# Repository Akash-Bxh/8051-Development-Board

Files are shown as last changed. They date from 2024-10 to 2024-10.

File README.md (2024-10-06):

# Building an 8051 Microcontroller Development Board
Material: KiCAD software, AT895S2, PCB, soldering kit, capacitor, resistor, display, 7-segment, push button, connector, buzzer, Ferric Chloride, Acetone, Fine abrasive sand paper, etc.

An 8051 Development Board is a hardware platform for projects involving the 8051 microcontroller. It includes the microcontroller, clock and reset circuits, power supply, I/O and peripheral interfaces (ADC, DAC), and supports various development tools. Users can write programs in assembly or high-level languages, compile them, and load them onto the board using assemblers and debuggers.

## Steps to make an 8051 Development Board:
* Design the Circuit: Use PCB design software like KiCAD to design the circuit and choose appropriate footprints for each component. Generate the Gerber files for the design.
* Print the Circuit on Raw PCB: Use the screen printing method to transfer the circuit design onto the raw PCB. Apply ink through a stencil and let it dry near warm air for 20-25 minutes.
* Etching Process: Submerge the PCB in ferric chloride solution to remove unwanted copper. After 10-15 minutes, clean the PCB with acetone to remove excess ink.
* Drilling: Drill holes in the PCB where electronic components will be mounted.
* Footprint Placement: Attach the printed component layout on the non-copper side to guide component placement.
* Soldering Components: Insert components on the PCB and solder them securely to the copper side.

## Applications and Uses of this 8051 Development Board
* Microcontroller Programming: It allows users to load and test programs written for the 8051 microcontroller, typically in assembly or C, through an assembler and debugger.
* Hardware Testing and Development: The board provides an environment for testing I/O ports and peripheral interfaces (ADC, DAC) connected to the 8051 microcontroller. It’s used for controlling devices or reading sensor data.
* Circuit Prototyping: The board is used for prototyping embedded system designs before transferring to a final PCB design for production.
* Peripheral Interfacing: You can connect and control components like sensors, displays, and actuators, making it suitable for hardware projects and experiments.
* Learning Platform: Ideal for education in embedded systems, giving students and developers hands-on experience with 8051 microcontrollers.

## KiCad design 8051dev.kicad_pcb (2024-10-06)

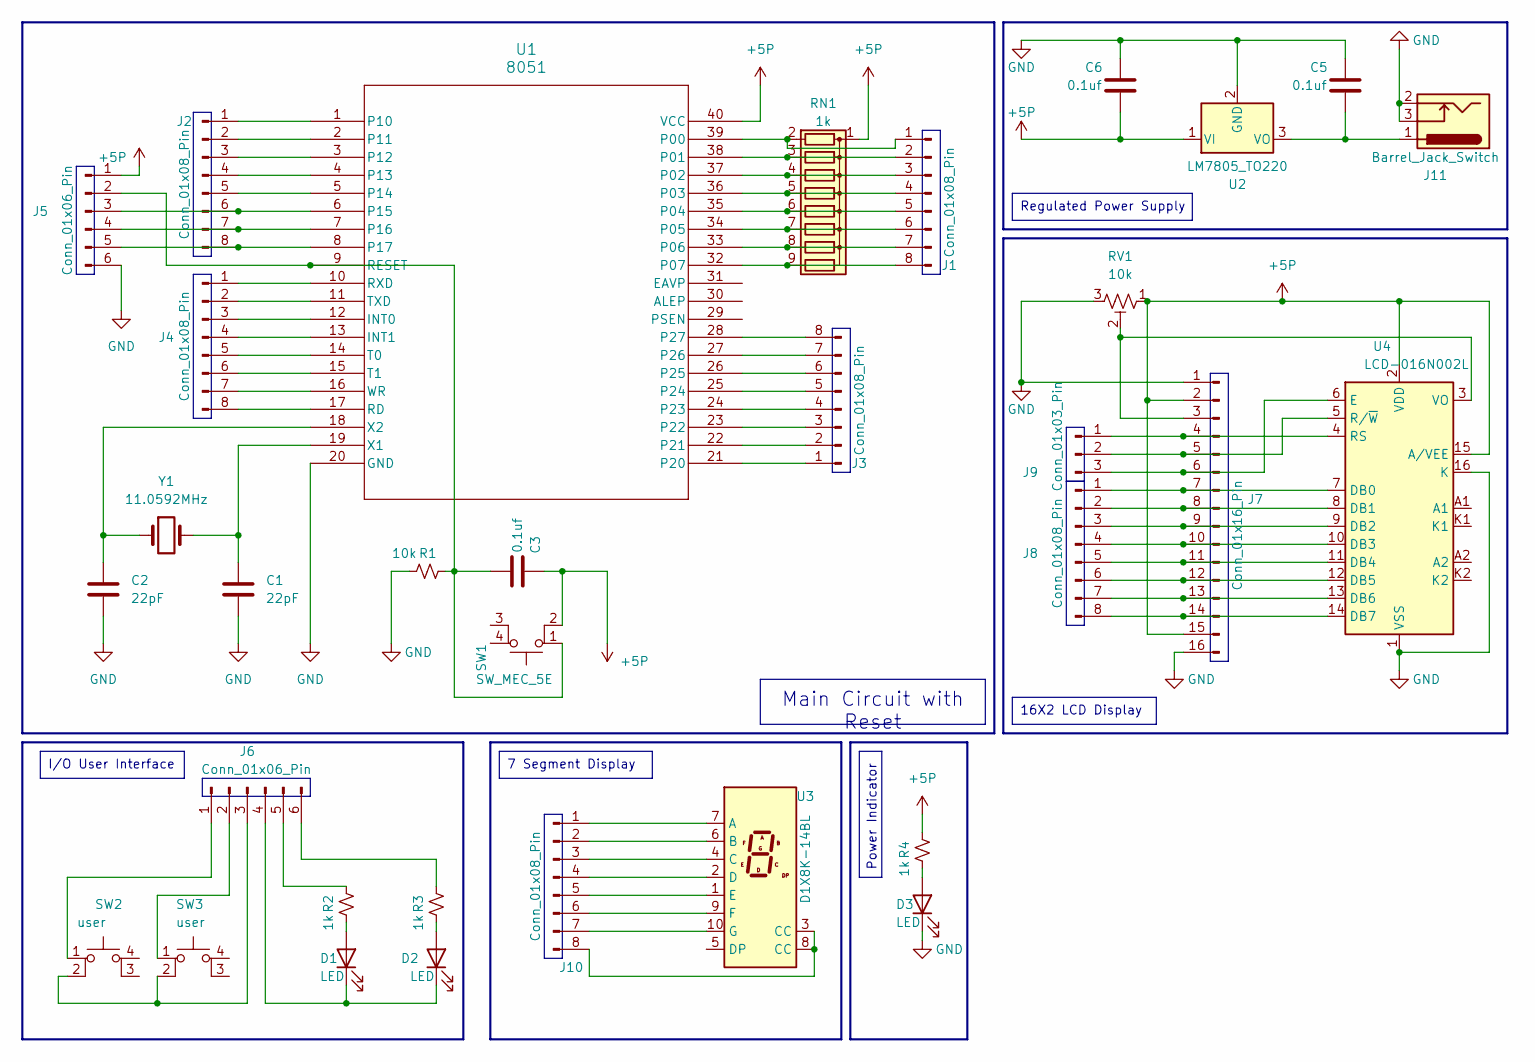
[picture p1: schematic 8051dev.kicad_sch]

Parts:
C1, C2: 22pF; C_Disc_D3.8mm_W2.6mm_P2.50mm
C3, C5, C6: 0.1uf; C_Disc_D3.8mm_W2.6mm_P2.50mm
D1, D2, D3: LED; LED_D5.0mm_Clear
J1, J2, J3, J4, J8, J10: Conn_01x08_Pin; PinHeader_1x08_P2.54mm_Vertical
J5, J6: Conn_01x06_Pin; PinHeader_1x06_P2.54mm_Vertical
J7: Conn_01x16_Pin; PinHeader_1x16_P2.54mm_Vertical
J9: Conn_01x03_Pin; PinHeader_1x03_P2.54mm_Vertical
J11: Barrel_Jack_Switch; BarrelJack_Horizontal
R1: 10k; R_Axial_DIN0207_L6.3mm_D2.5mm_P10.16mm_Horizontal
R2, R3: 1k; R_Axial_DIN0204_L3.6mm_D1.6mm_P2.54mm_Vertical
R4: 1k; R_Axial_DIN0207_L6.3mm_D2.5mm_P10.16mm_Horizontal
RN1: 1k; R_Array_SIP9
RV1: 10k; Potentiometer_ACP_CA6-H2,5_Horizontal
SW1: SW_MEC_5E; SW_PUSH_6mm_H4.3mm
SW2, SW3: user; SW_PUSH_6mm_H4.3mm
U1: 8051; DIP-40_W15.24mm
U2: LM7805_TO220; TO-220-3_Vertical
U3: D1X8K-14BL; 7SegmentLED_LTS6760_LTS6780
U4: LCD-016N002L
Y1: 11.0592MHz; Crystal_HC18-U_Vertical

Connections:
+5P: C3.1, C6.2, J5.1, J7.2, J7.15, R4.1, RN1.1 (common), RV1.1, SW1.2, U1.40 (VCC), U2.1 (VI), U4.2 (VDD), U4.15 (A/VEE); also elsewhere on the board
GND: C1.2, C2.1, C5.1, C6.1, D3.1 (K), J5.6, J7.1, J7.16, J11.2, J11.3, R1.2, RV1.3, U1.20 (GND), U2.2 (GND), U4.1 (VSS), U4.16 (K); also elsewhere on the board
unnamed: D1.2 (A), R2.2
unnamed: D1.1 (K), D2.1 (K), J6.4
unnamed: D2.2 (A), R3.2
unnamed: D3.2 (A), R4.2
unnamed: J1.1, RN1.2 (R1), U1.39 (P00)
unnamed: J1.2, RN1.3 (R2), U1.38 (P01)
unnamed: J1.3, RN1.4 (R3), U1.37 (P02)
unnamed: J1.4, RN1.5 (R4), U1.36 (P03)
unnamed: J1.5, RN1.6 (R5), U1.35 (P04)
unnamed: J1.6, RN1.7 (R6), U1.34 (P05)
unnamed: J1.7, RN1.8 (R7), U1.33 (P06)
unnamed: J1.8, RN1.9 (R8), U1.32 (P07)
unnamed: J2.1, U1.1 (P10)
unnamed: J2.2, U1.2 (P11)
unnamed: J2.3, U1.3 (P12)
unnamed: J2.4, U1.4 (P13)
unnamed: J2.5, U1.5 (P14)
unnamed: J2.6, J5.3, U1.6 (P15)
unnamed: J2.7, J5.4, U1.7 (P16)
unnamed: J2.8, J5.5, U1.8 (P17)
unnamed: J3.1, U1.21 (P20)
unnamed: J3.2, U1.22 (P21)
unnamed: J3.3, U1.23 (P22)
unnamed: J3.4, U1.24 (P23)
unnamed: J3.5, U1.25 (P24)
unnamed: J3.6, U1.26 (P25)
unnamed: J3.7, U1.27 (P26)
unnamed: J3.8, U1.28 (P27)
unnamed: J4.1, U1.10 (RXD)
unnamed: J4.2, U1.11 (TXD)
unnamed: J4.3, U1.12 (INT0)
unnamed: J4.4, U1.13 (INT1)
unnamed: J4.5, U1.14 (T0)
unnamed: J4.6, U1.15 (T1)
unnamed: J4.7, U1.16 (WR)
unnamed: J4.8, U1.17 (RD)
unnamed: C3.2, J5.2, R1.1, SW1.1, U1.9 (RESET)
unnamed: J6.1, SW2.1
unnamed: J6.2, SW3.1
unnamed: J6.3, SW2.2, SW3.2
unnamed: J6.5, R2.1
unnamed: J6.6, R3.1
unnamed: J7.3, RV1.2, U4.3 (VO)
unnamed: J7.4, J9.1, U4.4 (RS)
unnamed: J7.5, J9.2, U4.5 (R/~W)
unnamed: J7.6, J9.3, U4.6 (E)
unnamed: J7.7, J8.1, U4.7 (DB0)
unnamed: J7.8, J8.2, U4.8 (DB1)
unnamed: J7.9, J8.3, U4.9 (DB2)
unnamed: J7.10, J8.4, U4.10 (DB3)
unnamed: J7.11, J8.5, U4.11 (DB4)
unnamed: J7.12, J8.6, U4.12 (DB5)
unnamed: J7.13, J8.7, U4.13 (DB6)
unnamed: J7.14, J8.8, U4.14 (DB7)
unnamed: J10.1, U3.7 (A)
unnamed: J10.2, U3.6 (B)
unnamed: J10.3, U3.4 (C)
unnamed: J10.4, U3.2 (D)
unnamed: J10.5, U3.1 (E)
unnamed: J10.6, U3.9 (F)
unnamed: J10.7, U3.10 (G)
unnamed: J10.8, U3.3 (CC), U3.8 (CC)
unnamed: C1.1, U1.19 (X1), Y1.2
unnamed: C2.2, U1.18 (X2), Y1.1
unnamed: C5.2, J11.1, U2.3 (VO)

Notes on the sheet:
I/O User Interface
Power Indicator
16X2 LCD Display
Main Circuit with Reset
7 Segment Display
Regulated Power Supply

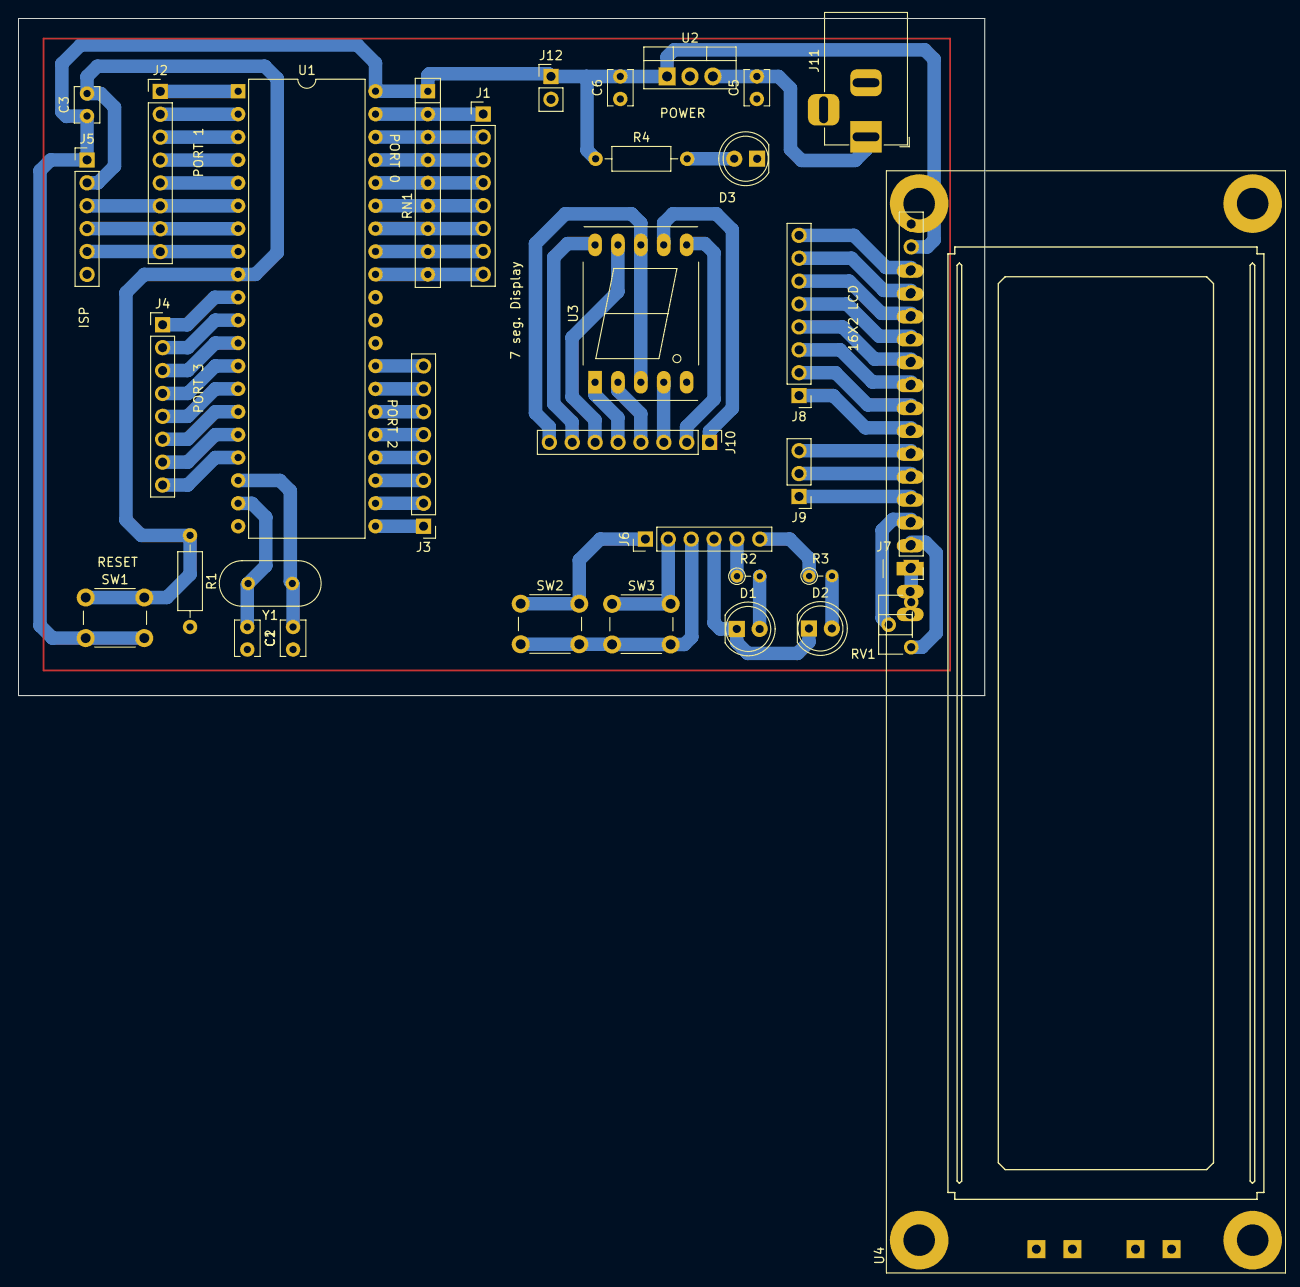
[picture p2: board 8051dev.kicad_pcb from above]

Board: 2 copper layers, 107.2 x 75.1 mm, 34 parts (0 on the bottom side), 67 nets.

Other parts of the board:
J12: 5v; PinHeader_1x02_P2.54mm_Vertical

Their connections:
+5P: J12.1; also elsewhere on the board
GND: J12.2; also elsewhere on the board
